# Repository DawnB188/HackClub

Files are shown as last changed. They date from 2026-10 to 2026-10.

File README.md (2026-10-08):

# HackClub
Documenting my HackClub journey!
This readme is telling my starbie story through pictures

This pic is the foorprints 
wk1 entry2 footprints

This is my arduino ide
wk1 entry2 arduino ide

this is one of the first pics i took when i started the project
wk1 entry1 photo

this is my kicad page
wk1 entry1 kicad

this was a bit tough to create, it is the pcb schematic and im super proud of myself for being able to figure things out
wk1 entry2 pcb schematic

This is the final pcb i'll probably post this on social media later because im also super proud that i was able to get this completed
wk1 entry2 pcb final

This is when i was assigning the footprints
wk 1 entry 2 assign foorprints

This i the schematic
wk1 entry 1 schematic

This is my project homepage on the half life website
wk 1 entry 3 project

This is a pic showing that i was able to successfully install all the necessary libraries and boards needed for this project to run successfully on my arduino ide
wk1 entry3 firmware

This is my git hub repo home page for the half life projects i will be doing
wk1 entry3 github

Believe in yourself guys and you too will be able to complete hardware projects. Thank you!

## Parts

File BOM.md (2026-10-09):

# Starbie – bill of materials

<!-- Generated by Half Life from project cmuv458yj0dbz01smoply2o25. Edits here are overwritten on the next sync. -->
<!-- Generated: 2026-10-09T03:39:09.681Z -->

> [!NOTE]
> This parts list is mirrored from [Half Life](https://halflife.hackclub.com). Editing it here will not change the platform's copy, and the next sync overwrites this file.

| Week | Tier | Parts funding |
| --- | --- | --- |
| Week 1 | Tier 1 | $30.00 |

| Part | What it's for | Qty | Unit | Total | Vendor |
| --- | --- | --- | --- | --- | --- |
| [Seeed Studio XIAO ESP32-C3](https://www.seeedstudio.com/Seeed-XIAO-ESP32C3-p-5431.html?utm_source=chatgpt.com) | Main microcontroller that runs Starbie's firmware | 1 | $4.99 | $4.99 | [Seeed Studio](https://www.seeedstudio.com/Seeed-XIAO-ESP32C3-p-5431.html?utm_source=chatgpt.com) |
| [Estardyn 0.96 Inch OLED SSD1306 White/Blue/Yellow 128X64 IIC I2C Serial Display Module 12864 LCD Screen Board](https://www.aliexpress.us/item/3256807631610005.html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) | Displays Starbie's face and animations | 1 | $2.77 | $2.77 | [Estardyn Flagship Store](https://www.aliexpress.us/item/3256807631610005.html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) |
| [Gateron Switches Mechanical Keyboard KS-9 3 Pin Red Brown Blue Green White RGB Silent Clicky Linear Tactile Compatible C](https://www.aliexpress.us/item/3256812389157712.html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) | Buttons for the Starbie project | 1 | $5.01 | $5.01 | [Jihua Electronics Store](https://www.aliexpress.us/item/3256812389157712.html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) |
| [1pcs GY521 GY-521 MPU6050 IIC I2C Interface 3 Axis Analog Gyroscope Sensor Accelerometer Compatible Module for Arduino](https://www.aliexpress.us/item/3256811885180989.html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) | Gyroscope for acceleration | 1 | $1.09 | $1.09 | [Electronic DIY Store](https://www.aliexpress.us/item/3256811885180989.html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) |
| [10PCS/lot Single Bus Digital Temperature and Humidity Sensor DHT11 Module Electronic Bricks KY-015](https://www.aliexpress.us/item/3256809040855978.html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) | Temperature and Humidity Sensor | 1 | $5.63 | $5.63 | [Liancheng Electronics (Shenzhen) Co.](https://www.aliexpress.us/item/3256809040855978.html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) |
| [Javino 5Pcs 1x40 Pin Connector Header Strip Male Female Header Single Row 40 Pin 2.54mm Pin Connector Strip Round  Needl](https://www.aliexpress.us/item/3256810450538744.html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) | Connector for J1 & J2 | 1 | $3.42 | $3.42 | [Javino Tec Store](https://www.aliexpress.us/item/3256810450538744.html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) |
| **Parts subtotal** | — | — | — | **$22.91** | — |
| **Tax & shipping** | — | — | — | **$1.26** | — |
| **Total** | — | — | — | **$24.17** | — |

$5.83 left of the tier's funding.

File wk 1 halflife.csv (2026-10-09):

Reference | Qty | Value | DNP | Exclude from BOM | Exclude from Board | Exclude from Simulation | Exclude from Position Files | Footprint | Datasheet
J1 | 1 | Conn_01x04_Pin |  |  |  |  | ${EXCLUDE_FROM_POS_FILES} | Imported Parts:Display_128x64_096_I2C
J2 | 1 | Conn_01x08_Pin |  |  |  |  | ${EXCLUDE_FROM_POS_FILES} | Connector_PinHeader_2.54mm:PinHeader_1x08_P2.54mm_Vertical
R1 | 1 | 10k |  |  |  |  | ${EXCLUDE_FROM_POS_FILES} | Resistor_THT:R_Axial_DIN0204_L3.6mm_D1.6mm_P7.62mm_Horizontal
SW1,SW2 | 2 | SW_Push |  |  |  |  | ${EXCLUDE_FROM_POS_FILES} | Button_Switch_Keyboard:SW_Cherry_MX_1.00u_PCB
U1 | 1 | DHT11 |  |  |  |  | ${EXCLUDE_FROM_POS_FILES} | Sensor:Aosong_DHT11_5.5x12.0_P2.54mm | http://akizukidenshi.com/download/ds/aosong/DHT11.pdf
U2 | 1 | XIAO-ESP32-C3-SMD |  |  |  |  | ${EXCLUDE_FROM_POS_FILES} | Imported Parts:XIAO-ESP32-C6-DIP

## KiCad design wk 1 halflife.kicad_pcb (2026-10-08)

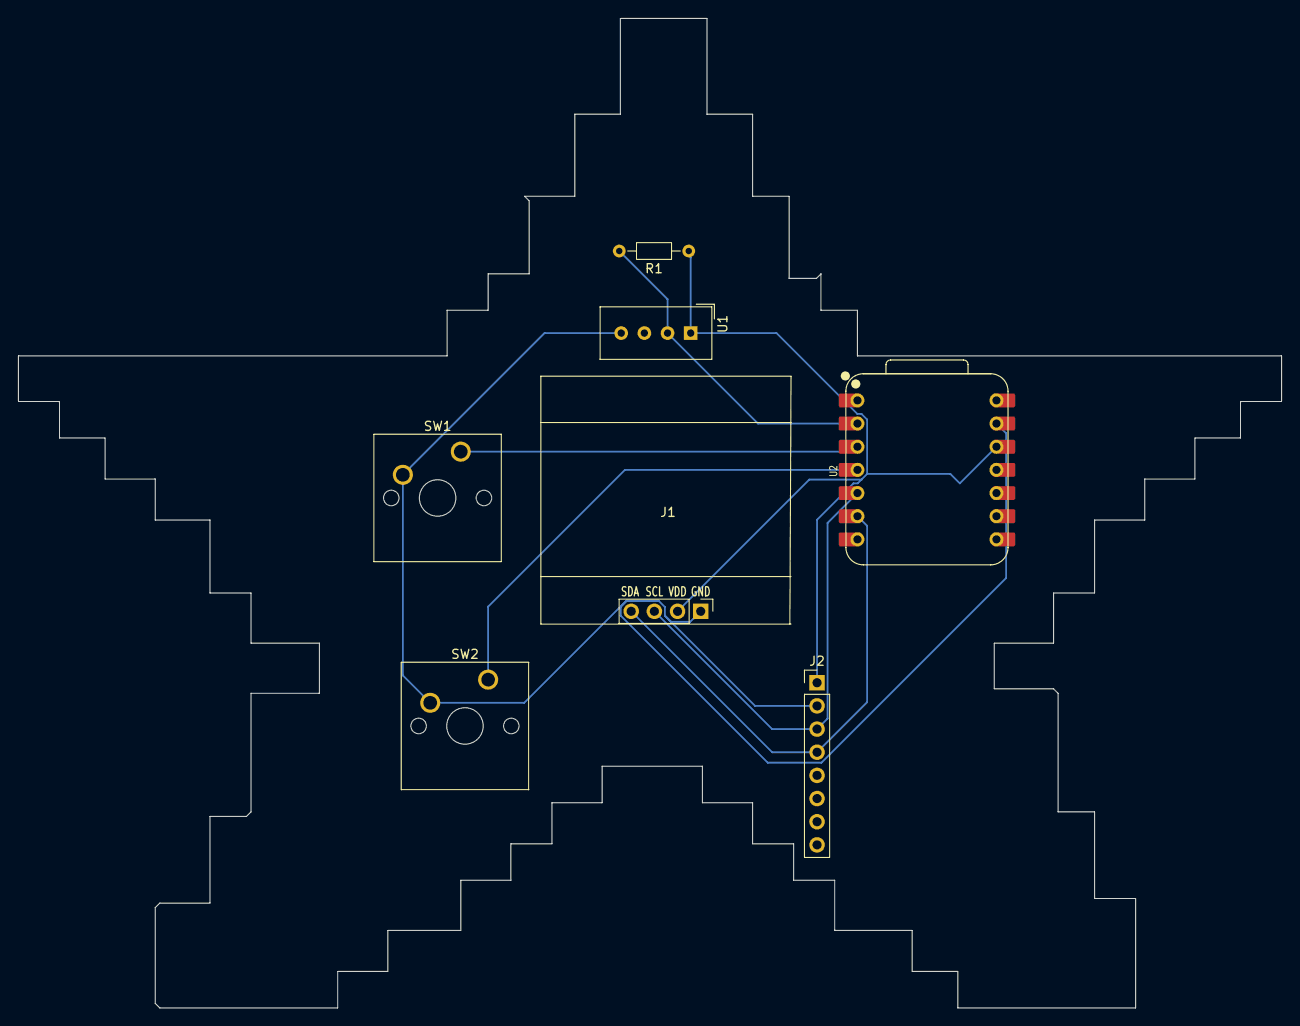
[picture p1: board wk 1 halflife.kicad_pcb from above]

Board: 2 copper layers, 138.5 x 108.5 mm, 7 parts (0 on the bottom side), 7 nets.

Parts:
J1: Conn_01x04_Pin; Display_128x64_096_I2C
J2: Conn_01x08_Pin; PinHeader_1x08_P2.54mm_Vertical
R1: 10k; R_Axial_DIN0204_L3.6mm_D1.6mm_P7.62mm_Horizontal
SW1, SW2: SW_Push; SW_Cherry_MX_1.00u_PCB
U1: DHT11; Aosong_DHT11_5.5x12.0_P2.54mm
U2: XIAO-ESP32-C3-SMD; XIAO-ESP32-C6-DIP

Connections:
+3.3V: J1.2, J2.1, R1.1, U1.1 (VDD), U2.12 (3V3_OUT)
/DHT11 DATA: R1.2, U1.2 (DATA), U2.2 (D1)
/GPIO2: SW1.1, U2.3 (D2)
/GPIO3: SW2.1, U2.4 (D3)
/SCL: J1.3, J2.3, U2.5 (D4)
/SDA: J1.4, J2.4, U2.6 (D5)
GND: J1.1, J2.2, SW1.2, SW2.2, U1.4 (GND), U2.13 (GND)

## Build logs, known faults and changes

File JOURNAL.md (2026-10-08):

# Starbie – devlog

<!-- Generated by Half Life from project cmuv458yj0dbz01smoply2o25. Edits here are overwritten on the next sync. -->
<!-- Generated: 2026-10-08T22:05:41.442Z -->

> [!NOTE]
> This devlog is mirrored from [Half Life](https://halflife.hackclub.com). Editing it here will not change the platform's copy, and the next sync overwrites this file.

> A tiny motion-controlled digital pet, basically a desktop Tamagotchi. Totally not a Starboy.

| Week | Tier | Hours logged | Entries |
| --- | --- | --- | --- |
| Week 1 | Tier 1 | 10h | 3 |

## Contents

1. [2026-10-07 – October 6,](#2026-10-07-october-6)
2. [2026-10-08 – October 8,](#2026-10-08-october-8)
3. [2026-10-08 – October 8,](#2026-10-08-october-8)

## Design

### 2026-10-07 – October 6,

**3h**

October 6,
Today I started working on the Starbie project by reading the how to make your own Starbie guide. I first downloaded the care package then I unzipped the file.

October 7,
Today, I installed KiCad and I watched youtube videos explaining how to install the symbol and footprint libraries.
Next, i started the project and added all the symbols and connected them as instructed in the guide.

wk1 entry1 photo

wk1 entry 1 schematic

wk1 entry1 kicad

### 2026-10-08 – October 8,

**4h**

October 8,

Today, I started by updating the PCB from my schematic. I created a custom boundry on the edge cuts layer using a guide on kicad website and arranged my components inside of it. Then I routed the PCB. Next, I used the DRC (or Design Rules Check) to check the PCB for design mistakes. Then I got tons of warnings and it took me like 2 hours to fix the missing connections.
Lastly, I installed esp32 on my Arduino ide.

wk1 entry2 footprints

wk1 entry2 pcb schematic

wk1 entry2 pcb final

wk1 entry2 arduino ide

### 2026-10-08 – October 8,

**3h**

October 8,

So later during the day I was able to finish up the firmware by ensuring the xiao esp32 was showing up in my arduino ide. Then i went over to my git hub and i updated things on there and I updated my project profile on the half life website.

wk1 entry3 firmware

wk 1 entry 3 project

wk1 entry3 github

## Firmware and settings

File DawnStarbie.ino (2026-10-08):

#include <Wire.h>
#include <Adafruit_GFX.h>
#include <Adafruit_SSD1306.h>
#include <Adafruit_MPU6050.h>
#include <DHT.h>
#include <Preferences.h>
#include <math.h>

// Board pins
const int I2C_SDA_PIN = 6;       // XIAO D4: OLED + MPU6050 SDA
const int I2C_SCL_PIN = 7;       // XIAO D5: OLED + MPU6050 SCL
const int DHT_PIN = 3;           // XIAO D1: DHT11 data
const int BUTTON_ONE_PIN = 4;    // XIAO D2: opens/confirms the radial menu
const int BUTTON_TWO_PIN = 5;    // XIAO D3: shows/hides stats

const bool USE_DHT11 = true;

const uint8_t OLED_ADDRESS = 0x3C;
const uint8_t MPU6050_ADDRESS = 0x68;

const int STARTING_JOY = 70;
const int STARTING_ENERGY = 75;
const int STARTING_FULLNESS = 65;

const bool RESET_SAVED_PET_ON_BOOT = true;

//Radial menu
enum PetReaction {
  NAP_REACTION,
  JUMP_REACTION,
  HEART_REACTION,
  RUN_REACTION,
};

struct MenuItem {
  const char *label;
  int joyChange;
  int energyChange;
  int fullnessChange;
  PetReaction reaction;
};

const MenuItem MENU_ITEMS[] = {
  {"NAP",   1,  18, -4, NAP_REACTION},   // top: sleep and emit Zs
  {"PLAY", 12, -9, -5, RUN_REACTION},    // right: two fast laps + hearts
  {"FEED",  3,  2,  18, JUMP_REACTION},  // bottom: wiggle and jump
  {"PET",   7,  0,  0, HEART_REACTION},  // left: jump and emit hearts
};
const int MENU_ITEM_COUNT = sizeof(MENU_ITEMS) / sizeof(MENU_ITEMS[0]);

//Movement feel
const float MENU_TILT_LIMIT = 6.0f;

const bool SWAP_MPU_AXES = true;
const float MENU_X_DIRECTION = 1.0f;
const float MENU_Y_DIRECTION = -1.0f;

const float MENU_CENTER_DEADZONE = 0.8f;
const float SHAKE_THRESHOLD = 7.0f;

const int SHAKE_JOY_CHANGE = 5;
const int SHAKE_ENERGY_CHANGE = -2;
const int SHAKE_FULLNESS_CHANGE = -1;

//Pet bitmap and animation
const int PET_SPRITE_WIDTH = 32;
const int PET_SPRITE_HEIGHT = 32;

const uint16_t PET_WALK_PIXEL_MS = 70;
const uint16_t PET_PRE_JUMP_MS = 230;
const uint16_t PET_JUMP_MS = 430;
const int PET_JUMP_HEIGHT = 16;
const uint32_t NAP_DURATION_MS = 48000;  
const uint16_t HEARTS_DURATION_MS = 1600;
const uint16_t PLAY_LAP_MS = 800;
const uint8_t PLAY_LAP_COUNT = 2;

const uint8_t PROGMEM PET_SPRITE[] = {
  0x00, 0x00, 0x00, 0x00,
  0x00, 0x00, 0x00, 0x00,
  0x00, 0x00, 0x00, 0x00,
  0x00, 0x00, 0x00, 0x00,
  0x00, 0x00, 0x00, 0x00,
  0x00, 0x00, 0x00, 0x00,
  0x00, 0x70, 0x0a, 0x00,
  0x00, 0xf8, 0x1f, 0x00,
  0x00, 0x8c, 0x3f, 0x80,
  0x00, 0x43, 0xff, 0x00,
  0x00, 0x43, 0xff, 0x00,
  0x00, 0x30, 0x7e, 0x00,
  0x00, 0x98, 0x01, 0x00,
  0x01, 0x98, 0x01, 0x80,
  0x03, 0x00, 0x10, 0xc0,
  0x03, 0x04, 0x00, 0xc0,
  0x01, 0x8b, 0x01, 0x80,
  0x01, 0xcb, 0x03, 0x80,
  0x03, 0xc0, 0x03, 0xc0,
  0x03, 0xc0, 0x03, 0xc0,
  0x01, 0xc0, 0x03, 0x80,
  0x01, 0x80, 0x01, 0x80,
  0x00, 0x60, 0x06, 0x00,
  0x00, 0x3f, 0xfc, 0x00,
  0x00, 0x7f, 0xfe, 0x00,
  0x00, 0x70, 0x0e, 0x00,
  0x00, 0x00, 0x00, 0x00,
  0x00, 0x00, 0x00, 0x00,
  0x00, 0x00, 0x00, 0x00,
  0x00, 0x00, 0x00, 0x00,
  0x00, 0x00, 0x00, 0x00,
  0x00, 0x00, 0x00, 0x00,
};
// ===========================================================================

const int SCREEN_WIDTH = 128;
const int SCREEN_HEIGHT = 64;
const int MENU_CENTER_X = 64;
const int MENU_CENTER_Y = 32;
const int MENU_ITEM_X[] = {64, 108, 64, 20};
const int MENU_ITEM_Y[] = {12, 32, 53, 32};
const int MENU_BALL_X_RANGE = 37;
const int MENU_BALL_Y_RANGE = 22;
const uint16_t BUTTON_DEBOUNCE_MS = 30;
const uint16_t MPU_READ_INTERVAL_MS = 30;
const uint16_t DHT_READ_INTERVAL_MS = 2200;
const uint16_t SHAKE_COOLDOWN_MS = 650;
const float STANDARD_GRAVITY = 9.80665f;

Adafruit_SSD1306 display(SCREEN_WIDTH, SCREEN_HEIGHT, &Wire, -1);
Adafruit_MPU6050 mpu;
DHT dht(DHT_PIN, DHT11);
Preferences preferences;

struct PetState {
  int joy;
  int energy;
  int fullness;
};

struct ButtonState {
  int pin;
  bool stableState;
  bool lastRawState;
  uint32_t lastChangedAt;
};

enum View {
  PET_VIEW,
  MENU_VIEW,
  STATS_VIEW,
};

PetState pet = {STARTING_JOY, STARTING_ENERGY, STARTING_FULLNESS};
ButtonState buttonOne = {BUTTON_ONE_PIN, HIGH, HIGH, 0};
ButtonState buttonTwo = {BUTTON_TWO_PIN, HIGH, HIGH, 0};
View currentView = PET_VIEW;

bool mpuFound = false;
bool dhtFound = false;
float accelerationX = 0.0f;
float accelerationY = 0.0f;
float accelerationZ = STANDARD_GRAVITY;
float temperatureC = NAN;
float humidity = NAN;
float menuBallX = MENU_CENTER_X;
float menuBallY = MENU_CENTER_Y;
float menuCenterAccelerationX = 0.0f;
float menuCenterAccelerationY = 0.0f;
int selectedMenuItem = -1;
uint32_t lastMpuReadAt = 0;
uint32_t lastDhtReadAt = 0;
uint32_t lastShakeAt = 0;
uint32_t shakeAnimationEndsAt = 0;
uint32_t petJumpStartedAt = 0;
uint32_t nappingUntil = 0;
uint32_t heartAnimationEndsAt = 0;
uint32_t playRunStartedAt = 0;
int nappingPetX = 0;

int petWalkingX(uint32_t now);

int keepInRange(int value, int smallest, int largest) {
  return constrain(value, smallest, largest);
}

void changePet(int joyChange, int energyChange, int fullnessChange) {
  pet.joy = keepInRange(pet.joy + joyChange, 0, 100);
  pet.energy = keepInRange(pet.energy + energyChange, 0, 100);
  pet.fullness = keepInRange(pet.fullness + fullnessChange, 0, 100);
}

void loadPet() {
  preferences.begin("starbie", false);
  if (RESET_SAVED_PET_ON_BOOT) {
    preferences.clear();
  }
  pet.joy = preferences.getInt("joy", STARTING_JOY);
  pet.energy = preferences.getInt("energy", STARTING_ENERGY);
  pet.fullness = preferences.getInt("full", STARTING_FULLNESS);
}

void savePet() {
  preferences.putInt("joy", pet.joy);
  preferences.putInt("energy", pet.energy);
  preferences.putInt("full", pet.fullness);
}

void setUpButton(ButtonState &button) {
  pinMode(button.pin, INPUT_PULLUP);
  button.stableState = digitalRead(button.pin);
  button.lastRawState = button.stableState;
  button.lastChangedAt = millis();
}

// Returns true exactly once for each press, even if the switch bounces.
bool wasPressed(ButtonState &button) {
  const bool rawState = digitalRead(button.pin);
  const uint32_t now = millis();

  if (rawState != button.lastRawState) {
    button.lastRawState = rawState;
    button.lastChangedAt = now;
  }

  if (rawState != button.stableState &&
      now - button.lastChangedAt >= BUTTON_DEBOUNCE_MS) {
    button.stableState = rawState;
    return button.stableState == LOW;
  }

  return false;
}

void updateMpu() {
  if (!mpuFound || millis() - lastMpuReadAt < MPU_READ_INTERVAL_MS) {
    return;
  }
  lastMpuReadAt = millis();

  sensors_event_t acceleration;
  sensors_event_t gyro;
  sensors_event_t sensorTemperature;
  mpu.getEvent(&acceleration, &gyro, &sensorTemperature);
  accelerationX = acceleration.acceleration.x;
  accelerationY = acceleration.acceleration.y;
  accelerationZ = acceleration.acceleration.z;
}

void updateDht() {
  if (!dhtFound || millis() - lastDhtReadAt < DHT_READ_INTERVAL_MS) {
    return;
  }
  lastDhtReadAt = millis();

  const float newHumidity = dht.readHumidity();
  const float newTemperatureC = dht.readTemperature();
  if (!isnan(newHumidity)) {
    humidity = newHumidity;
  }
  if (!isnan(newTemperatureC)) {
    temperatureC = newTemperatureC;
  }
}

int petWalkingX(uint32_t now) {
  const int farthestX = SCREEN_WIDTH - PET_SPRITE_WIDTH;
  const uint32_t roundTrip = static_cast<uint32_t>(farthestX) * 2;
  const uint32_t step = (now / PET_WALK_PIXEL_MS) % roundTrip;
  return step <= farthestX ? step : roundTrip - step;
}

uint32_t playRunDuration() {
  return static_cast<uint32_t>(PLAY_LAP_MS) * PLAY_LAP_COUNT;
}

bool isNapping() {
  return nappingUntil != 0 && millis() < nappingUntil;
}

bool isPlaying() {
  return playRunStartedAt != 0 && millis() - playRunStartedAt < playRunDuration();
}

int playRunX(uint32_t now) {
  const int farthestX = SCREEN_WIDTH - PET_SPRITE_WIDTH;
  const uint32_t lapAge = (now - playRunStartedAt) % PLAY_LAP_MS;
  const float progress = static_cast<float>(lapAge) / PLAY_LAP_MS;
  return progress < 0.5f ? static_cast<int>(progress * 2.0f * farthestX)
                         : static_cast<int>((1.0f - progress) * 2.0f * farthestX);
}

void updatePetTimers() {
  if (nappingUntil != 0 && !isNapping()) {
    nappingUntil = 0;  // The pet wakes naturally when its nap time is over.
  }
  if (playRunStartedAt != 0 && !isPlaying()) {
    playRunStartedAt = 0;  // PLAY is exactly two left-to-right-to-left laps.
  }
}

// While the menu is open, the MPU6050 acts like a tiny air mouse. The position
// at the instant Button 1 opens the menu becomes the center for that menu use.
void updateMenuBall() {
  float xTilt = accelerationX - menuCenterAccelerationX;
  float yTilt = accelerationY - menuCenterAccelerationY;

  if (SWAP_MPU_AXES) {
    const float oldXTilt = xTilt;
    xTilt = yTilt;
    yTilt = oldXTilt;
  }
  xTilt = constrain(xTilt * MENU_X_DIRECTION, -MENU_TILT_LIMIT, MENU_TILT_LIMIT);
  yTilt = constrain(yTilt * MENU_Y_DIRECTION, -MENU_TILT_LIMIT, MENU_TILT_LIMIT);
  const float targetX = MENU_CENTER_X + (xTilt / MENU_TILT_LIMIT) * MENU_BALL_X_RANGE;
  const float targetY = MENU_CENTER_Y + (yTilt / MENU_TILT_LIMIT) * MENU_BALL_Y_RANGE;

  // This small amount of smoothing makes the ball feel less jittery.
  menuBallX += (targetX - menuBallX) * 0.20f;
  menuBallY += (targetY - menuBallY) * 0.20f;

  // The menu has four full sectors, not four tiny targets. Any tilt direction
  // past the center dead zone selects its matching top/right/bottom/left action.
  if (fabsf(xTilt) < MENU_CENTER_DEADZONE && fabsf(yTilt) < MENU_CENTER_DEADZONE) {
    selectedMenuItem = -1;
  } else if (fabsf(xTilt) > fabsf(yTilt)) {
    selectedMenuItem = xTilt > 0.0f ? 1 : 3;  // right or left
  } else {
    selectedMenuItem = yTilt > 0.0f ? 2 : 0;  // bottom or top
  }
}

void checkForShake() {
  if (!mpuFound || currentView != PET_VIEW) {
    return;
  }

  const float magnitude = sqrtf(accelerationX * accelerationX +
                                accelerationY * accelerationY +
                                accelerationZ * accelerationZ);
  const uint32_t now = millis();
  if (fabsf(magnitude - STANDARD_GRAVITY) >= SHAKE_THRESHOLD &&
      now - lastShakeAt >= SHAKE_COOLDOWN_MS) {
    lastShakeAt = now;
    nappingUntil = 0;  // A shake wakes a sleeping pet right away.
    shakeAnimationEndsAt = now + 350;
    changePet(SHAKE_JOY_CHANGE, SHAKE_ENERGY_CHANGE, SHAKE_FULLNESS_CHANGE);
    savePet();
  }
}

void openMenu() {
  currentView = MENU_VIEW;
  selectedMenuItem = -1;
  menuBallX = MENU_CENTER_X;
  menuBallY = MENU_CENTER_Y;
  // Calibrate here so every menu starts from however the builder is holding it.
  menuCenterAccelerationX = accelerationX;
  menuCenterAccelerationY = accelerationY;
}

void chooseMenuItem() {
  if (selectedMenuItem == -1) {
    return;  // Keep the menu open until the ball reaches a choice.
  }

  const MenuItem &item = MENU_ITEMS[selectedMenuItem];
  changePet(item.joyChange, item.energyChange, item.fullnessChange);
  savePet();
  const uint32_t now = millis();
  nappingUntil = 0;
  heartAnimationEndsAt = 0;
  playRunStartedAt = 0;

  if (item.reaction == NAP_REACTION) {
    petJumpStartedAt = 0;
    nappingPetX = petWalkingX(now);
    nappingUntil = now + NAP_DURATION_MS;
  } else if (item.reaction == RUN_REACTION) {
    petJumpStartedAt = 0;
    playRunStartedAt = now;
    heartAnimationEndsAt = now + playRunDuration();
  } else {
    // A confirmed action gets a little anticipation shake before the jump.
    petJumpStartedAt = now;
    if (item.reaction == HEART_REACTION) {
      heartAnimationEndsAt = now + HEARTS_DURATION_MS;
    }
  }
  currentView = PET_VIEW;
}

void handleButtons() {
  if (wasPressed(buttonOne)) {
    if (currentView == MENU_VIEW) {
      chooseMenuItem();
    } else {
      openMenu();
    }
  }

  if (wasPressed(buttonTwo)) {
    // Button 2 never changes the pet. It only lets you peek at the values.
    currentView = currentView == STATS_VIEW ? PET_VIEW : STATS_VIEW;
  }
}

void drawHeart(int x, int y) {
  // A tiny seven-pixel-wide heart that stays crisp on the OLED.
  display.fillRect(x - 2, y, 2, 2, SSD1306_WHITE);
  display.fillRect(x + 1, y, 2, 2, SSD1306_WHITE);
  display.fillRect(x - 3, y + 2, 7, 2, SSD1306_WHITE);
  display.fillRect(x - 2, y + 4, 5, 1, SSD1306_WHITE);
  display.fillRect(x - 1, y + 5, 3, 1, SSD1306_WHITE);
  display.drawPixel(x, y + 6, SSD1306_WHITE);
}

void drawHearts(uint32_t now, int petX, int petY) {
  if (now >= heartAnimationEndsAt) {
    return;
  }

  const float progress =
      1.0f - static_cast<float>(heartAnimationEndsAt - now) / HEARTS_DURATION_MS;
  const int rise = static_cast<int>(progress * 18.0f);
  drawHeart(petX + 10, petY - 3 - rise);
  drawHeart(petX + 22, petY - 9 - rise / 2);
}

void drawSleepZs(uint32_t now, int petX, int petY) {
  // The Zs float upward, then loop back down while the pet is napping.
  const int rise = static_cast<int>((now / 300UL) % 15UL);
  display.setTextSize(1);
  display.setTextColor(SSD1306_WHITE);
  display.setCursor(petX + 23, petY - 2 - rise);
  display.print("z");
  display.setCursor(petX + 28, petY - 8 - rise / 2);
  display.print("z");
}

void drawPet() {
  display.clearDisplay();

  const uint32_t now = millis();
  int petX = isNapping() ? nappingPetX : petWalkingX(now);
  if (isPlaying()) {
    petX = playRunX(now);
  }
  int petY = SCREEN_HEIGHT - PET_SPRITE_HEIGHT;

  // The pet always wanders except during a nap; PLAY temporarily takes over.
  if (now < shakeAnimationEndsAt) {
    petX += static_cast<int>(sinf(now / 18.0f) * 3.0f);
  }

  if (!isNapping() && petJumpStartedAt != 0) {
    const uint32_t animationAge = now - petJumpStartedAt;

    if (animationAge < PET_PRE_JUMP_MS) {
      petX += static_cast<int>(sinf(now / 16.0f) * 3.0f);
    } else if (animationAge < PET_PRE_JUMP_MS + PET_JUMP_MS) {
      const float jumpProgress =
          static_cast<float>(animationAge - PET_PRE_JUMP_MS) / PET_JUMP_MS;
      petY -= static_cast<int>(sinf(jumpProgress * PI) * PET_JUMP_HEIGHT);
    } else {
      petJumpStartedAt = 0;
    }
  }

  petX = constrain(petX, 0, SCREEN_WIDTH - PET_SPRITE_WIDTH);
  display.drawBitmap(petX, petY, PET_SPRITE, PET_SPRITE_WIDTH, PET_SPRITE_HEIGHT,
                     SSD1306_WHITE);

  if (isNapping()) {
    drawSleepZs(now, petX, petY);
  }
  drawHearts(now, petX, petY);
}

void drawMenuItem(int item) {
  const int boxWidth = 33;
  const int boxHeight = 12;
  const int boxX = MENU_ITEM_X[item] - boxWidth / 2;
  const int boxY = MENU_ITEM_Y[item] - boxHeight / 2;
  const bool isSelected = item == selectedMenuItem;

  if (isSelected) {
    display.fillRoundRect(boxX, boxY, boxWidth, boxHeight, 3, SSD1306_WHITE);
    display.setTextColor(SSD1306_BLACK);
  } else {
    display.drawRoundRect(boxX, boxY, boxWidth, boxHeight, 3, SSD1306_WHITE);
    display.setTextColor(SSD1306_WHITE);
  }

  display.setTextSize(1);
  const int labelLength = strlen(MENU_ITEMS[item].label);
  display.setCursor(MENU_ITEM_X[item] - labelLength * 3, MENU_ITEM_Y[item] - 3);
  display.print(MENU_ITEMS[item].label);
  display.setTextColor(SSD1306_WHITE);
}

void drawMenu() {
  display.clearDisplay();
  // The two diagonal lines divide the screen into four big selection sectors.
  display.drawLine(0, 0, SCREEN_WIDTH - 1, SCREEN_HEIGHT - 1, SSD1306_WHITE);
  display.drawLine(0, SCREEN_HEIGHT - 1, SCREEN_WIDTH - 1, 0, SSD1306_WHITE);
  for (int item = 0; item < MENU_ITEM_COUNT; item++) {
    drawMenuItem(item);
  }

  display.drawCircle(MENU_CENTER_X, MENU_CENTER_Y, 11, SSD1306_WHITE);
  display.fillCircle(static_cast<int>(menuBallX), static_cast<int>(menuBallY), 4,
                     SSD1306_WHITE);
}

void drawStatBar(int y, const char *label, int value) {
  display.setTextSize(1);
  display.setTextColor(SSD1306_WHITE);
  display.setCursor(4, y);
  display.print(label);
  display.drawRect(48, y, 57, 8, SSD1306_WHITE);
  display.fillRect(49, y + 1, map(value, 0, 100, 0, 55), 6, SSD1306_WHITE);
  display.setCursor(109, y);
  display.print(value);
}

void drawStats() {
  display.clearDisplay();
  drawStatBar(5, "JOY", pet.joy);
  drawStatBar(20, "ENERGY", pet.energy);
  drawStatBar(35, "FULL", pet.fullness);

  display.setCursor(4, 53);
  if (!isnan(temperatureC)) {
    display.print("TEMP ");
    display.print(static_cast<int>(temperatureC));
    display.print("C");
  } else {
    display.print("TEMP --");
  }

  display.setCursor(76, 53);
  if (!isnan(humidity)) {
    display.print("H ");
    display.print(static_cast<int>(humidity));
    display.print("%");
  } else {
    display.print("H --");
  }
}

void drawCurrentView() {
  if (currentView == MENU_VIEW) {
    drawMenu();
  } else if (currentView == STATS_VIEW) {
    drawStats();
  } else {
    drawPet();
  }
  display.display();
}

void setup() {
  Serial.begin(115200);
  Wire.begin(I2C_SDA_PIN, I2C_SCL_PIN);
  setUpButton(buttonOne);
  setUpButton(buttonTwo);
  loadPet();

  if (!display.begin(SSD1306_SWITCHCAPVCC, OLED_ADDRESS)) {
    Serial.println("OLED not found. Check power, GND, SDA, SCL, and address.");
    while (true) {
      delay(10);
    }
  }

  mpuFound = mpu.begin(MPU6050_ADDRESS, &Wire);
  if (mpuFound) {
    mpu.setAccelerometerRange(MPU6050_RANGE_8_G);
    mpu.setGyroRange(MPU6050_RANGE_500_DEG);
    mpu.setFilterBandwidth(MPU6050_BAND_21_HZ);
  } else {
    Serial.println("MPU6050 not found. The menu will not move until it is connected.");
  }

  if (USE_DHT11) {
    dht.begin();
    dhtFound = true;
  }

  drawCurrentView();
}

void loop() {
  updateMpu();
  updateDht();
  updatePetTimers();
  handleButtons();

  if (currentView == MENU_VIEW) {
    updateMenuBall();
  } else {
    checkForShake();
  }

  drawCurrentView();
  delay(16);  
}
